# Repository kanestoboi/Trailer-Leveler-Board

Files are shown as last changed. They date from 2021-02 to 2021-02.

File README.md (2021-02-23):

# Trailer Leveler Board
This repository contains the PCB design of the Trailer Leveler project, a wireless trailer leveling system. The firmware for this board and Android application to connect to the device via Bluetooth LE can be found in the [Trailer Leveler Software](https://github.com/kanestoboi/Trailer-Leveler-Software) repository.

Features
* 16 bit, 3 axis accelerometer for precise angle measurement
* Circuity to support over the air (OTA) firmware upload using HM-11 BLE module
* Li-Po battery charging
* Battery overvoltage and undervoltage protection circuitry
* Internal 8 MHz oscillator used for clock to reduce BOM cost and power requirements
* Battery monitoring capability

## Photos
Images of the board can be found in the [images](https://github.com/kanestoboi/Trailer-Leveler-Board/tree/master/images) directory.

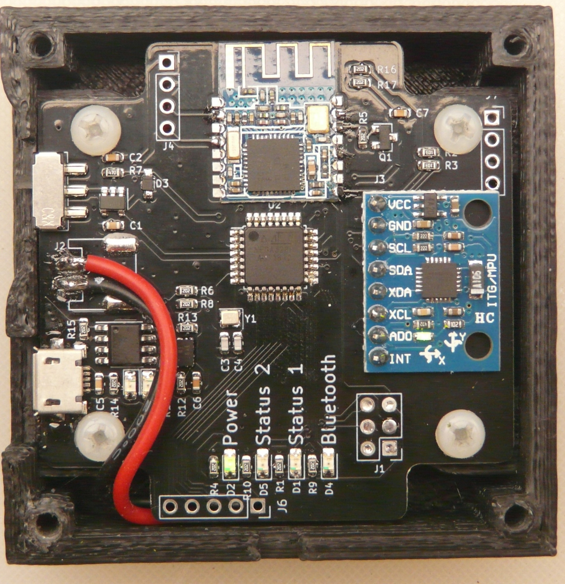
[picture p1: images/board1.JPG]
Complete Board


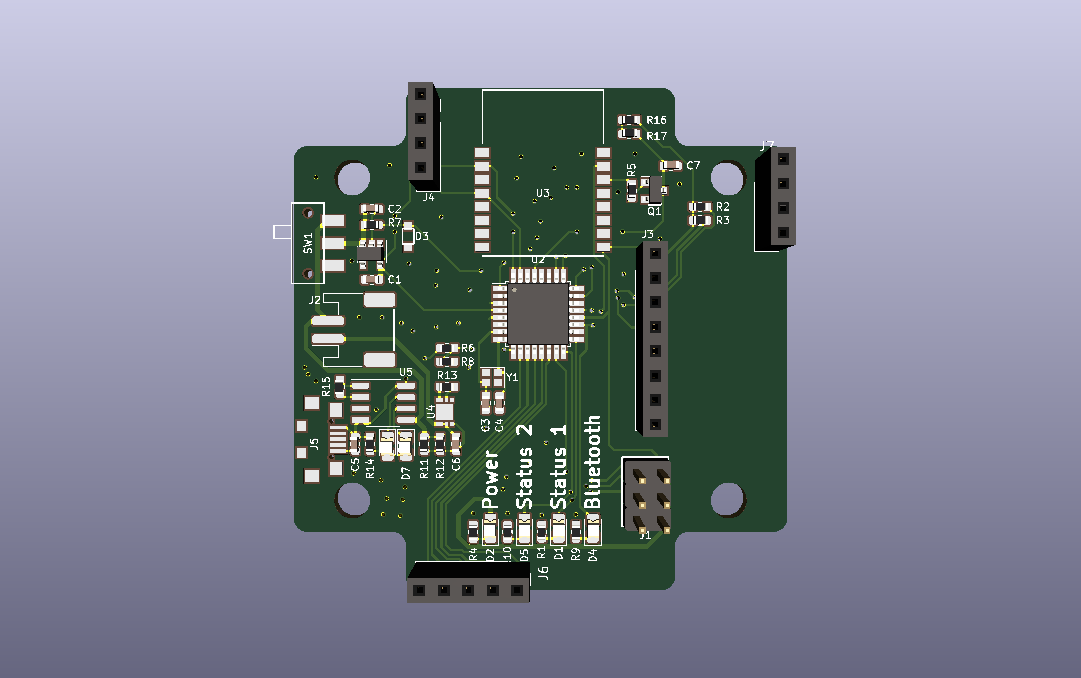
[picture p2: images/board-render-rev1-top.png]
Board Render Top


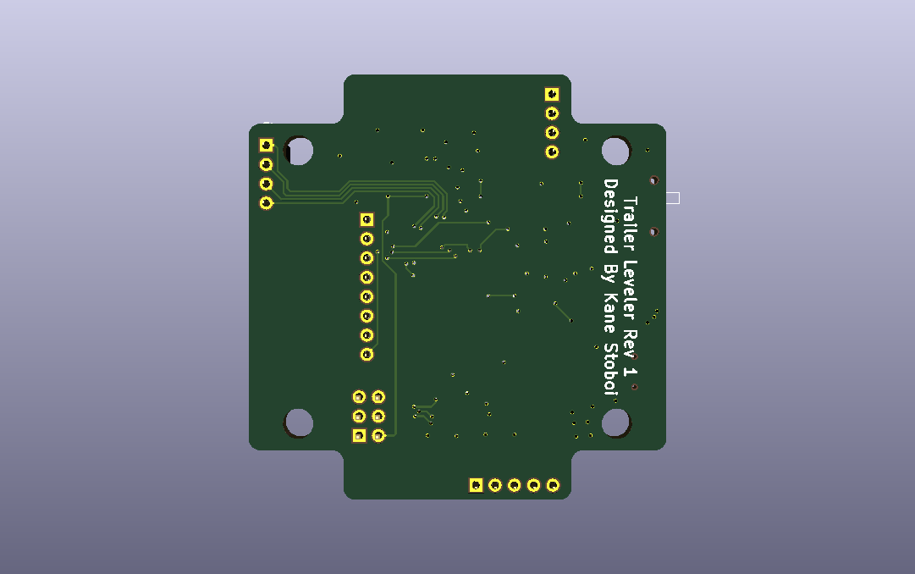
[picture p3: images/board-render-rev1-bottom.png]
Board Render Bottom


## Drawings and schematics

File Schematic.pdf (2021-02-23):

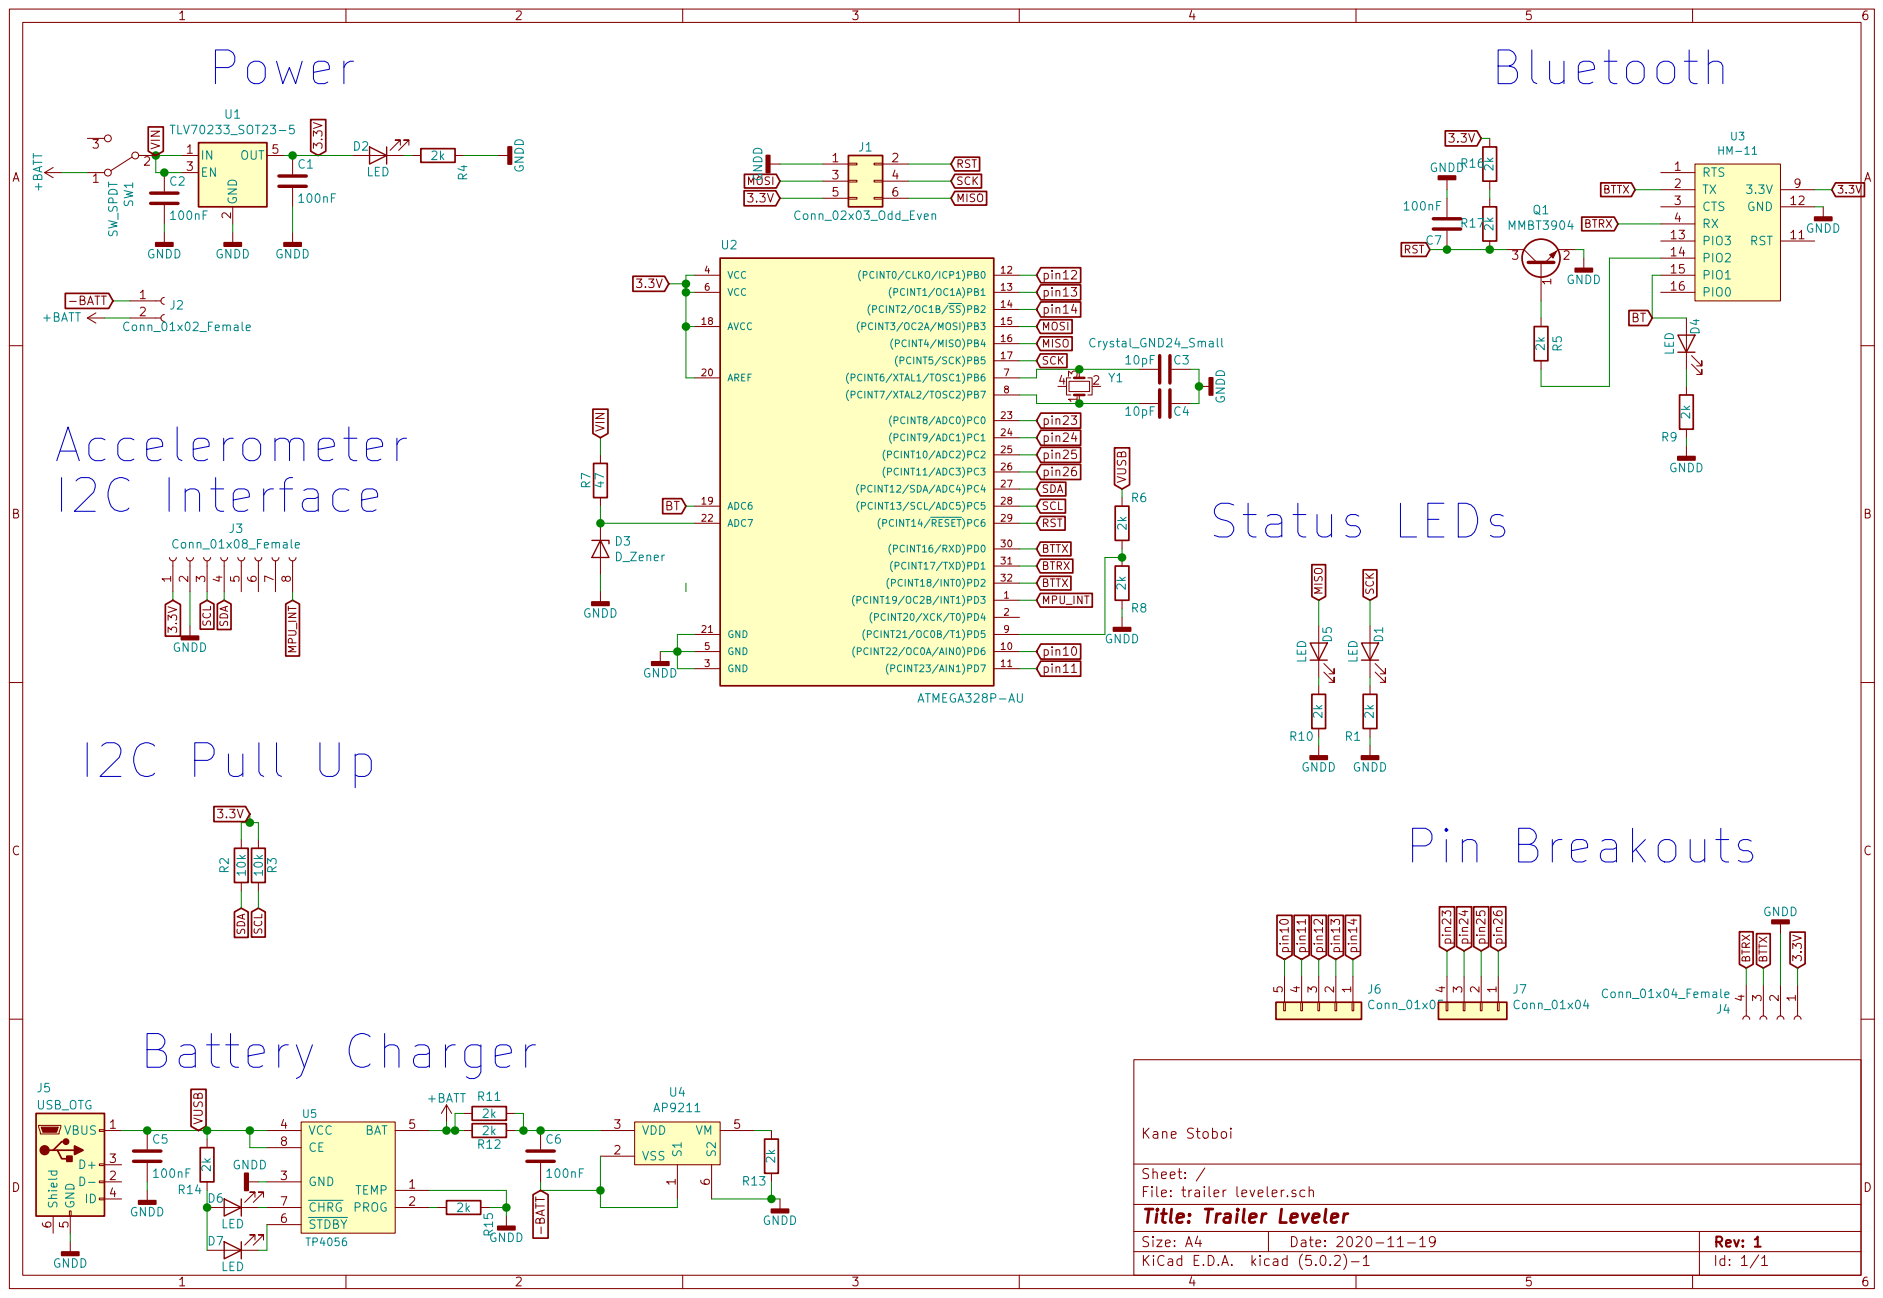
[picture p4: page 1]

Id: 1/1 Title: Trailer Leveler File: trailer leveler.sch Sheet: / Kane Stoboi

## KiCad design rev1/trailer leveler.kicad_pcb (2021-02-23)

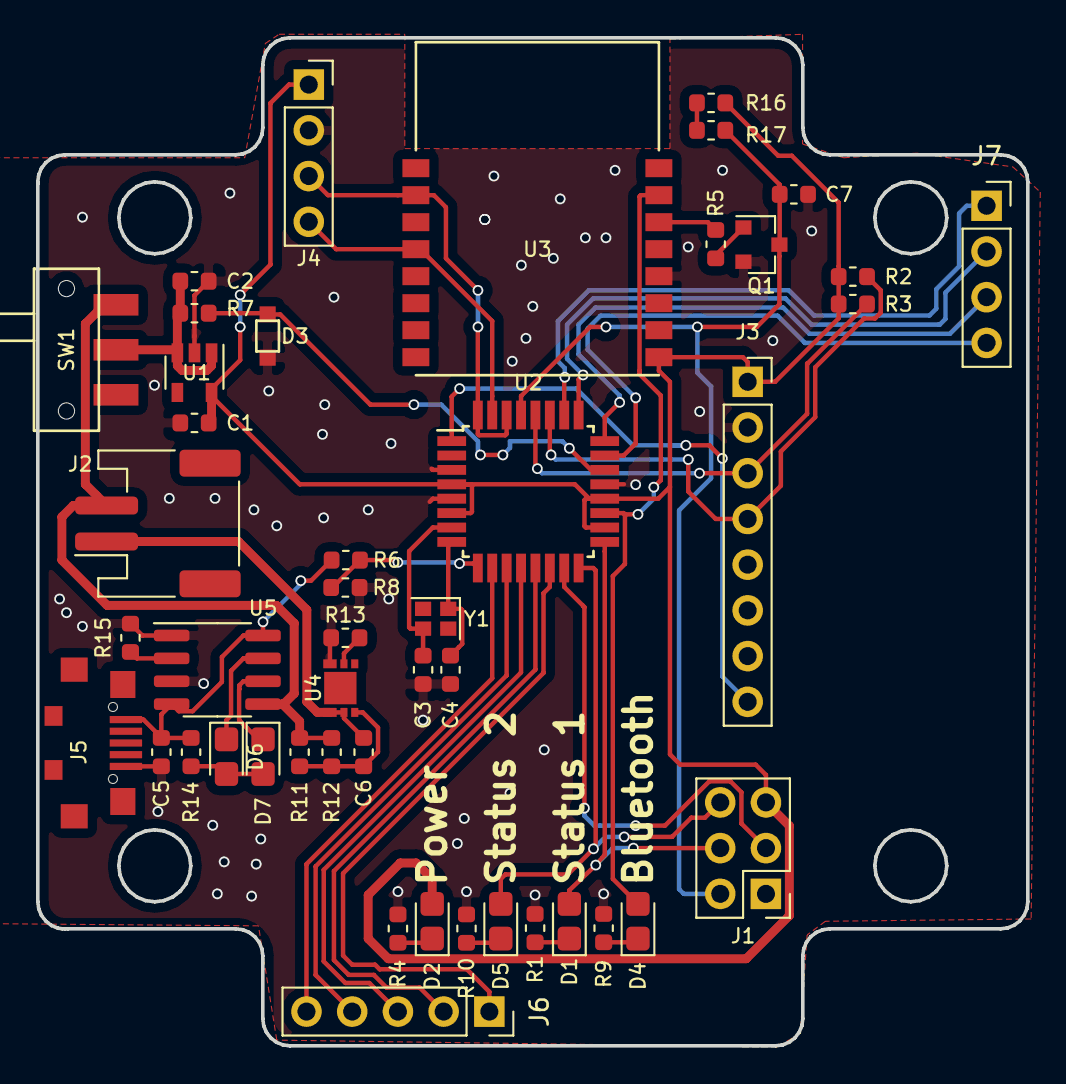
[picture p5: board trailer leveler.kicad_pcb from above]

Board: 2 copper layers, 55.0 x 56.0 mm, 46 parts (0 on the bottom side), 42 nets.

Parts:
C1, C2, C5, C6, C7: 100nF; C_0603_1608Metric
C3, C4: 10pF; C_0603_1608Metric
D1, D2, D4, D5, D6, D7: LED; LED_0805_2012Metric_Castellated
D3: D_Zener; SC-90A
J1: Conn_02x03_Odd_Even; Pin_Header_Straight_2x03_Pitch2.54mm
J2: Conn_01x02_Female; JST_PH_S2B-PH-SM4-TB_1x02-1MP_P2.00mm_Horizontal
J3: Conn_01x08_Female; PinSocket_1x08_P2.54mm_Vertical
J4: Conn_01x04_Female; PinSocket_1x04_P2.54mm_Vertical
J5: USB_OTG; USB_Micro_C77238
J6: Conn_01x05; PinSocket_1x05_P2.54mm_Vertical
J7: Conn_01x04; PinSocket_1x04_P2.54mm_Vertical
Q1: MMBT3904; SOT-23
R1, R4, R5, R6, R8, R9, R10, R11, R12, R13, R14, R15, R16, R17: 2k; R_0603_1608Metric
R2, R3: 10k; R_0603_1608Metric
R7: 47; R_0603_1608Metric
SW1: SW_SPDT; JS102011SAQN
U1: TLV70233_SOT23-5; SOT-23-5
U2: ATMEGA328P-AU; TQFP-32_7x7mm_Pitch0.8mm
U3: HM-11
U4: AP9211; U-DFN2030-6
U5: TP4056; SOP-8_3.76x4.96mm_P1.27mm
Y1: Crystal_GND24_Small; Crystal_SMD_2016-4Pin_2.0x1.6mm

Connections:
3.3V: C1.1, D2.2, J1.5, J3.1, J4.1, R2.1, R3.1, R16.2, U1.5, U2.4, U2.6, U2.18, U2.20, U3.9
+BATT: J2.2, R11.2, R12.2, SW1.1, U5.5
-BATT: C6.2, J2.1, U4.1, U4.2
BT: D4.2, U2.19, U3.15
BTRX: J4.4, U2.31, U3.4
BTTX: J4.3, U2.30, U2.32, U3.2
GNDD: C1.2, C2.2, C3.2, C4.2, C5.2, C7.2, D3.2, J1.1, J3.2, J4.2, J5.5, Q1.2, R1.1, R4.1, R8.1, R9.1, R10.1, R13.1, R15.1, U1.2, U2.3, U2.5, U2.21, U3.12, U4.6, U5.1, U5.3
MISO: D5.2, J1.6, U2.16
MOSI: J1.3, U2.15
MPU_INT: J3.8, U2.1
unnamed: C3.1, U2.7, Y1.3
unnamed: C4.1, U2.8, Y1.1
unnamed: C6.1, R11.1, R12.1, U4.3
unnamed: D1.1, R1.2
unnamed: D2.1, R4.2
unnamed: D3.1, R7.1, U2.22
unnamed: D4.1, R9.2
unnamed: D5.1, R10.2
unnamed: D6.1, U5.7
unnamed: D6.2, D7.2, R14.1
unnamed: D7.1, U5.6
unnamed: Q1.1, R5.2
unnamed: R5.1, U3.14
unnamed: R6.2, R8.2, U2.9
unnamed: R13.2, U4.5
unnamed: R15.2, U5.2
unnamed: R16.1, R17.2
RST: C7.1, J1.2, Q1.3, R17.1, U2.29
SCK: D1.2, J1.4, U2.17
SCL: J3.3, R3.2, U2.28
SDA: J3.4, R2.2, U2.27
VIN: C2.1, R7.2, SW1.2, U1.1, U1.3
VUSB: C5.1, J5.1, R6.1, R14.2, U5.4, U5.8
pin10: J6.5, U2.10
pin11: J6.4, U2.11
pin12: J6.3, U2.12
pin13: J6.2, U2.13
pin14: J6.1, U2.14
pin23: J7.4, U2.23
pin24: J7.3, U2.24
pin25: J7.2, U2.25
pin26: J7.1, U2.26
